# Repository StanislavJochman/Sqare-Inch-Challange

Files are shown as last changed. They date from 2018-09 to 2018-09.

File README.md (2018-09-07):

# Sqare-Inch-Challange
This Github Repository is for ESP8266 device which can measure data from sensors and upload them on GoogleDrive Sheets. Footprint of this device is 1x1 inch(25.4mm x 25.4mm)

## Order PCB
[OSH park](https://oshpark.com/shared_projects/sk7W7fMs)

## Komponents needed
* [PCB](https://raw.githubusercontent.com/StanislavJochman/Sqare-Inch-Challange/master/Gerber_Files.zip)
* [ESP8266](https://www.ebay.co.uk/itm/Profession-Esp-12E-ESP8266-Serial-Port-WIFI-Transceiver-Wireless-Module-AP-STA/163158011629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)
* [DS18B20](https://www.ebay.co.uk/itm/DS18B20-TO-92-9-12bit-Temperature-Sensor-Dallas-Thermometer-Temperature-Sensor/291950339086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)
* [DHT22](https://www.ebay.co.uk/itm/1-2-5-10PCS-DHT22-AM2302-Temperature-Humidity-Sensor-Replace-SHT11-SHT15-Module/272484297869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)
* [BMP180](https://www.ebay.com/itm/NEW-BMP180-BOSCH-Pressure-sensor-LGA-7-GOOD-QUALITY/282770708207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)/[BMP180 Module](https://www.ebay.co.uk/itm/BMP180-Replace-BMP085-Digital-Barometric-Pressure-Sensor-Board-Module-f-EA/362322141662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)
* [LDR](https://www.ebay.co.uk/itm/10PCS-Photoresistor-LDR-CDS-5mm-Resistor-Sensor-Light-Dependent-GL5516-ATF/192428070436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)
* [2 x 100n capacitor (0805)](https://www.ebay.co.uk/itm/50pcs-Case-0805-SMD-Capacitor-50V-100NF-10-X7R-CL21B104KBCNNNC/401367378177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)
* [2 x 10k resistor(0805)](https://www.ebay.co.uk/itm/100Pcs-Resistor-10K-Ohm-0805-Smd-Rohs-New-Ic/382469082086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)
* [2 x 4k7 resistor(0805)](https://www.ebay.co.uk/itm/100Pcs-Resistor-4K7-Ohm-0805-Smd-Rohs-Ic-New/132176766970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)
* [1 x 1k resistor(0805)](https://www.ebay.co.uk/itm/100Pcs-0805-Smd-Smt-1K-1Kohn-Value-5-Resistor-New-Ic/382469059974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)
## Price calculation
| Component | Price per 3 units |
|---|:---:|
| PCB | 5$ |
| ESP8266 | 6.09$ |
| DS18B20 | 3,78$ |
| DHT22 | 8,34$ |
| BMP180/BMP180 Modul | 5.4$/3,78$ |
| LDR | 1.26$ |
| 100n capacitor (0805) | 3.31$ |
| 10k resistors (0805)  | 1.26$ |
| 1k resistors (0805) | 1.26$ |
| 4k7 resistors (0805)  | 1.26$ |
|-----------------------|-------------------|
| Total: |  36,96$ / 35,34$  |

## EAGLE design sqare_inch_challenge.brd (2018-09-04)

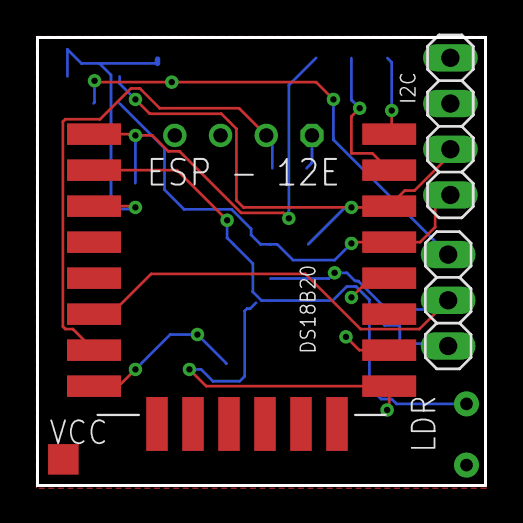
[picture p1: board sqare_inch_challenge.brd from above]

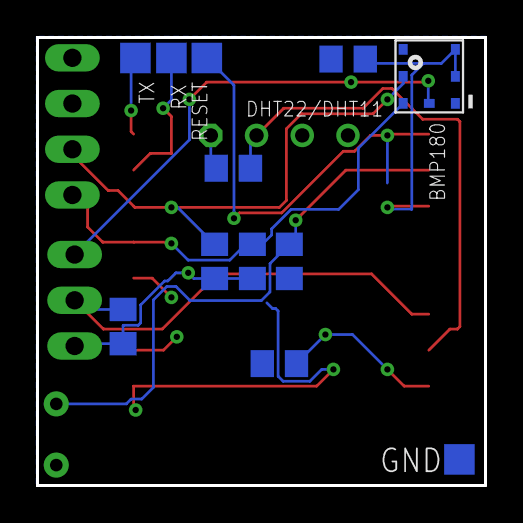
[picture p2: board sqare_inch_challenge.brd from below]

Board: 2 copper layers, 24.9 x 24.9 mm, 18 parts (13 on the bottom side), 10 nets.

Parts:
BMP180: BMP180
C1, C2: 100n; C0805
DHT22/DHT11: RHT03_DHT-22
DS18B20: 1X03
GND: GND; TP17SQ
I2C: 1X04
LDR: LDR; T0-46-A10XX
R5, R6: 10k; R0805
R7: 1k; R0805
R8, R9: 4k7; R0805
RESET: PTR1TP17SQ; TP17SQ
RX: PTR1TP17SQ; TP17SQ
TX: PTR1TP17SQ; TP17SQ
U1: ESP12E-SMD
VCC: +3V3; TP17SQ

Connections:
1W: DS18B20.2, R8.1, U1.GPIO12
+3V3: BMP180.2, BMP180.3, C1.1, C2.1, DHT22/DHT11.VDD, DS18B20.3, I2C.1, LDR.1, R5.2, R6.2, R8.2, R9.2, U1.CH_PD, U1.VCC, VCC.TP
DHT: DHT22/DHT11.DATA, R9.1, U1.GPIO13
GND: BMP180.7, C1.2, C2.2, DHT22/DHT11.GND, DS18B20.1, GND.TP, I2C.2, R7.1, U1.GND, U1.GPIO0, U1.GPIO15
LDR: LDR.2, R7.2, U1.ADC
RESET: RESET.TP, U1.RESET
RX: RX.TP, U1.RXD0
SCL: BMP180.5, I2C.3, R6.1, U1.GPIO5
SDA: BMP180.6, I2C.4, R5.1, U1.GPIO4
TX: TX.TP, U1.TXD0

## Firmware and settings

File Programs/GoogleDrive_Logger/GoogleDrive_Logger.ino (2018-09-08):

#include <ESP8266WiFi.h>
#include <ESP8266mDNS.h>
#include <WiFiUdp.h>
#include <ArduinoOTA.h>
#include <ESP8266HTTPClient.h>
#include "DHT.h"
#include <OneWire.h> 
#include <DallasTemperature.h>
#include <Wire.h>
#include <Adafruit_BMP085.h>


#define sleep_time 300
#define DHTTYPE DHT11
#define ONE_WIRE_BUS 12
#define dht_pin 13
#define LDR_pin A0

#define data1 t_ds
#define data2 h_dht
#define data3 l
#define data4 p_bmp
#define data5 a_bmp
#define data6 s_bmp


OneWire oneWire(ONE_WIRE_BUS);
WiFiServer TelnetServer(8266);
DHT dht(dht_pin, DHTTYPE); 
DallasTemperature sensors(&oneWire);
Adafruit_BMP085 bmp;

const char* ssid = "ssid";
const char* password = "password";

const String devid = "v2829F2D7DCB9358";
const String website = "http://api.pushingbox.com/pushingbox?devid="+devid;
String new_website = "";

void setup(void){
  if (!bmp.begin()) {
  Serial.println("Could not find a valid BMP085 sensor, check wiring!");
  while (1) {}
  }
  TelnetServer.begin();
  dht.begin();
  Serial.begin(115200);
  sensors.begin();
  WiFi.begin(ssid, password);
  while (WiFi.status() != WL_CONNECTED)
      {
        delay(1000);
        Serial.print(".");
      }
  ArduinoOTA.onStart([]() {
  Serial.println("OTA Start");
  });
  ArduinoOTA.onEnd([]() {
  Serial.println("OTA End");
  Serial.println("Rebooting...");
  });
  pinMode(2,OUTPUT);
  ArduinoOTA.onStart([]() {
  Serial.println("OTA Start");
  });
  ArduinoOTA.onEnd([]() {
  Serial.println("OTA End");
  Serial.println("Rebooting...");
  });
  ArduinoOTA.onProgress([](unsigned int progress, unsigned int total) {
  Serial.printf("Progress: %u%%\r\n", (progress / (total / 100)));
  });
  ArduinoOTA.onError([](ota_error_t error) {
  Serial.printf("Error[%u]: ", error);
  if (error == OTA_AUTH_ERROR) Serial.println("Auth Failed");
  else if (error == OTA_BEGIN_ERROR) Serial.println("Begin Failed");
  else if (error == OTA_CONNECT_ERROR) Serial.println("Connect Failed");
  else if (error == OTA_RECEIVE_ERROR) Serial.println("Receive Failed");
  else if (error == OTA_END_ERROR) Serial.println("End Failed");
  });
  ArduinoOTA.begin();
  Serial.println("Ready");
  Serial.print("IP address: ");
  Serial.println(WiFi.localIP());
  sensors.begin();
  
}
void loop(){
  ArduinoOTA.handle();
  digitalWrite(2,HIGH);
  sensors.requestTemperatures();
  float t_ds = sensors.getTempCByIndex(0); 
  float h_dht = dht.readHumidity();
  float t_dht = dht.readTemperature();
  int l = map(analogRead(LDR_pin),0,1023,0,100);
  float t_bmp = bmp.readTemperature();
  float p_bmp = bmp.readPressure();
  float a_bmp = bmp.readAltitude();
  float s_bmp = bmp.readSealevelPressure();

  if (t_ds!=-127&&!isnan(h_dht))
      {
        new_website = website+"&Data1="+String(data1)+"&Data2="+String(data2)+"&Data3="+String(data3)+"&Data4="+String(data4)+"&Data5="+String(data5)+"&Data6="+String(data6);
        Serial.println(new_website);
        if (WiFi.status() == WL_CONNECTED)
          {
            HTTPClient http;
            http.begin(new_website);
            int httpCode = http.GET();
            if (httpCode > 0)
              {
                String payload = http.getString();
              }
            http.end();
            delay(sleep_time*1000);
          }

      }
}

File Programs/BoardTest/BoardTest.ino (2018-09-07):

#include "DHT.h"        // including the library of DHT11 temperature and humidity sensor
#define DHTTYPE DHT11   // DHT 11
#include <OneWire.h>
#include <DallasTemperature.h>

#define ONE_WIRE_BUS 12
#define dht_pin 13
#define LDR_pin A0

OneWire oneWire(ONE_WIRE_BUS);
DHT dht(dht_pin, DHTTYPE); 
DallasTemperature sensors(&oneWire);

void setup(void){ 
  dht.begin();
  Serial.begin(115200);
  sensors.begin();

  
}
void loop(){
  sensors.requestTemperatures();
  float C = sensors.getTempCByIndex(0); 
  float h = dht.readHumidity();
  float t = dht.readTemperature();         
  Serial.print("humidity");
  Serial.print(h);
  Serial.print("%  ");
  Serial.print("temperature(DHT)");
  Serial.print(t); 
  Serial.print("C  ");
  Serial.print("temperature(DS18B20)");
  Serial.print(C);
  Serial.print("C  ");
  Serial.print("Light");
  Serial.print(map(analogRead(LDR_pin),0,1023,0,100));
  Serial.println("%");
}

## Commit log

2018-08-11 Gerbers
    Gerbers for ESP8266 1inch square datalogger
2018-08-11 Board file
    [sqare_inch_challenge.brd]
2018-08-11 Final Schematic
    [sqare_inch_challenge.sch]
2018-08-11 Final Board Files
    [sqare_inch_challenge.brd]
2018-09-04 Gerber files
2018-09-04 Board files
    [sqare_inch_challenge.brd]
2018-09-04 Schematic files
    [sqare_inch_challenge.sch]
